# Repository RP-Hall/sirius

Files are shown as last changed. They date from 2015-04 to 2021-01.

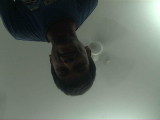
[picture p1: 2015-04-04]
MATLAB/matlab_camera/out_image.jpg

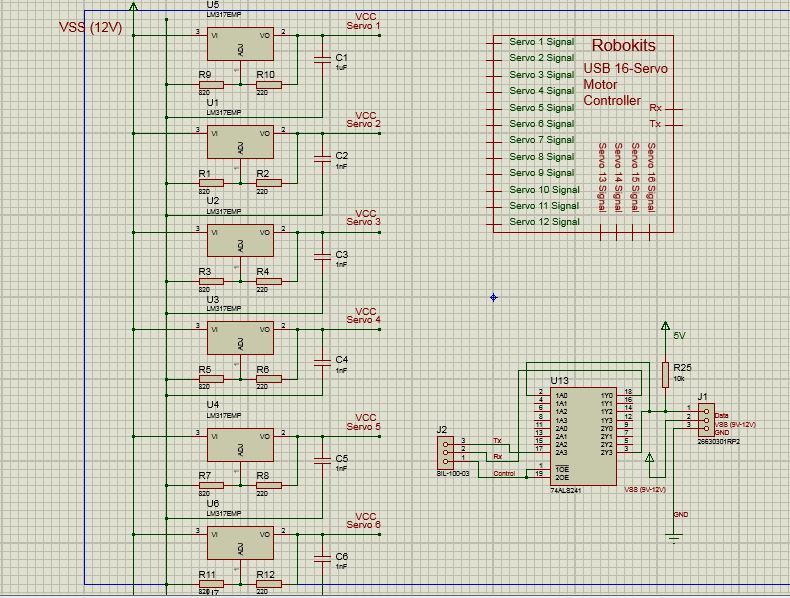
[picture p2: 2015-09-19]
Circuits/ckts.JPG

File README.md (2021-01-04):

# SIRIUS - A Wheel-Leg Transfigurable Robot

Sirius

## Video

Sirius Video (https://youtu.be/tceGkQNUUpM)

## Presentation
Sirius Presentation (http://www.slideshare.net/soumyadeepmukherjee17/hm2015-52970964)

## System Design

The following picture describe the system design of the robot:

Overall-Architecture

The following picture describes the control inputs to the robot:

Control-Architecture

## Circuitry

All schematics for embedded sub-systems are opened with 'Proteus' software

Sirius Circuitry

File: powerSirius.pdsprj: Proteus files for schematics

Schematic contents:  
1. Servo power system (Left)  
2. Robokits 16-Servo Motor Controller (Right Top)  
3. Communication System for Dynamixel (Right Bottom)

## File Explorer

Controller:  AtMEGA2560
Board used: [AtMEGA2560 Development Board](http://www.nex-robotics.com/products/microcontroller-development-boards/atmega2560-development-board.html)

### AVR
* Gait_Testing.c: File for testing gaits and debugging
* USART.c:	Functions for serial communication
* usart.h: 	Header for USART.c
* config.c:	Contains configurations for all gaits
* config.h: 	Header for config.c
* dynamixel.h dynamixel.c:	Files for running Dynamixels
* lcd.h lcd.c:	Files for showing output on LCD (connected at PORTD)	
* main.h: For running main process (different gaits)
* motion.h motion.c:	Files for motion of legs
* roboservo.h roboservo.c:	File for running servo motors

### Gaits
* backspider: Spider gait backwards
* home:	Home orientations
* littledog_gait: Dog gait
* little_gait_quasi: Quasi dog gait
* roll_gait: Wheel gait
* rotation_gait: Rotation
* spiderwalk: Spider gait

### MATLAB

* matlab_camera:
	** camera.m: Gets camera feed
	** imageConvert.py: Convert binary format image to jpeg
	** image_raw.txt: Raw image text file through camera
	** out_image.jpg: Output image
	** rawtoimage.m: MATLAB function to convert binary to image jpg

* matlab_inverse_kinematics:
	* acceptable_angles.txt: Text File to store acceptable angles after Gait Generation
	* angle_conversion_even.m: Convert Angles according to contraints for even angles
	* angle_conversion_odd: Convert Angles according to contraints for even angles
	* gait.m: File to calculate possible gaits
	* inversekinematics.m: Solves inverse kinematic equations
	* packet_angles.txt: Stores the angles to be sent as packet via serial
	* packet_generation.m: Generates packet format text file to be sent

### Serial_Testing
C++ Code for sending angles via serial communication.
* main.cpp:	main process
* serial.h serial.cpp: Serial Implementation

## Mechanical Design
All Solidworks Parts are uploaded.

Sirius Mechanical Design

Sirius Wheel Design

## References

[1] Kenjiro TADAKUMA(Osaka Univ.) et. al, Mechanical Design of the Wheel-Leg Hybrid Mobile Robot to Realize a Large Wheel Diameter. IEEE/RSJ International Conference on Intelligent Robots and Systems, Taipei, Taiwan, 2010  
[2] Carlos Queiroz, Nuno Gon ?calves and Paulo Menezes, A study on Static Gaits for a Four Leg Robot, CONTROL 2000, International Conference on, At Cambridge, UK  
[3] Nils Brynedal Ignell,Niclas Rasmusson and Johan Matsson, An overview of legged and wheeled robotic locomotion. IRCSE ’12. IDT Mini-conference on Interesting Results in Computer Science and Engineering, Sweden, 2012  
[4] Raibert, M. H. Legged Robots Communications of the ACM 499, June 1986 Volume 29 Number 6 http://www.universelle-automation.de/1980 Boston.pdf  
[5] Buckley D. 2011 http://davidbuckley.net/DB/HistoryMakers.htm  
[6] Arikawa, K., Hirose, S., 2007 Mechanical design of walking machines Philosophical Transactions of the Royal Society A 365  
[7] Heikkil,M.,Pietikinen,M.andSchmid,C.(2009),DescriptionofInter- est Regions with Local Binary Patterns. Pattern Recognition 42(3):425-436.  
[8] Christian Weiss,Nikolas Fechner,Matthias Stark and Andreas Zell,Comparison of Different Approaches to Vibration-based Terrain Clas- sification, ECMR07  

## Team
* Captains
	* Aditya Tiwari
	* Diwakar Paliwal
	* Vinay Varma
	* Sai Prasad Arkal
* Rest
	* Keshav Sarraf
	* Soumyadeep Mukherjee
	* Rishal Raj
	* Vishnu Sharma
	* Aman Gupta
	* Nipurn Gulgulia
	* Raushan Kumar
	* Kawaljeet Kumar
	* Divya Prakash
	* Seemant Jay
	* Rahul Singh
	* Kumar Abhinav

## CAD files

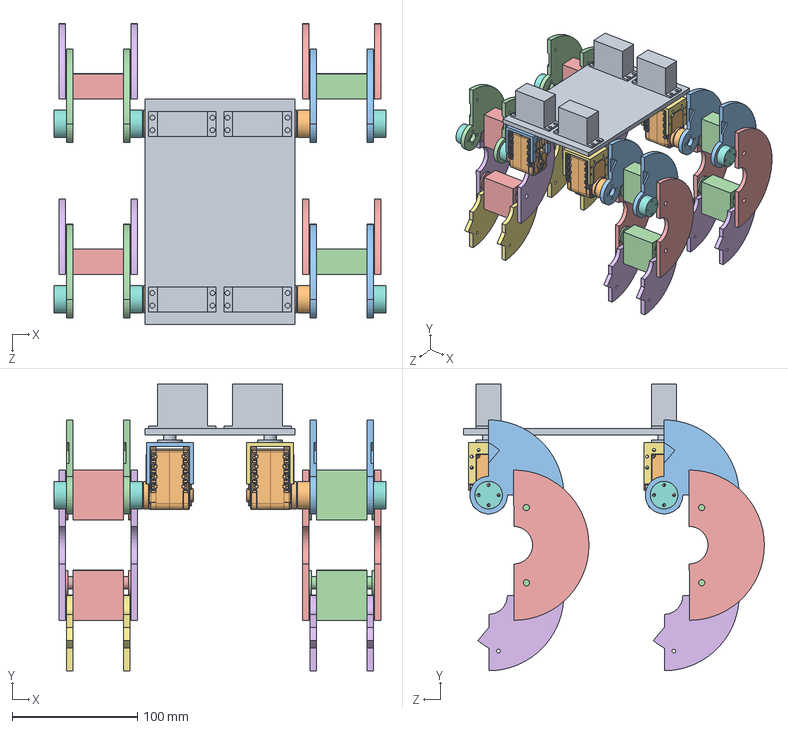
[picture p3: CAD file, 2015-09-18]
MechD/PsyBot Assembly.SLDASM
265.0 x 228.7 x 240.1 mm
Base
Dynamixel AX12 x 4
Arm Connector x 2
thigh x 4
servo x 4
calf x 4
foot x 4
DynExtender x 6
Topservo x 4
MirrorDynExtender x 2
Mirrorthigh x 4
Mirrorservo x 4
Mirrorcalf x 4
Mirrorfoot x 4
MirrorArm Connector x 2

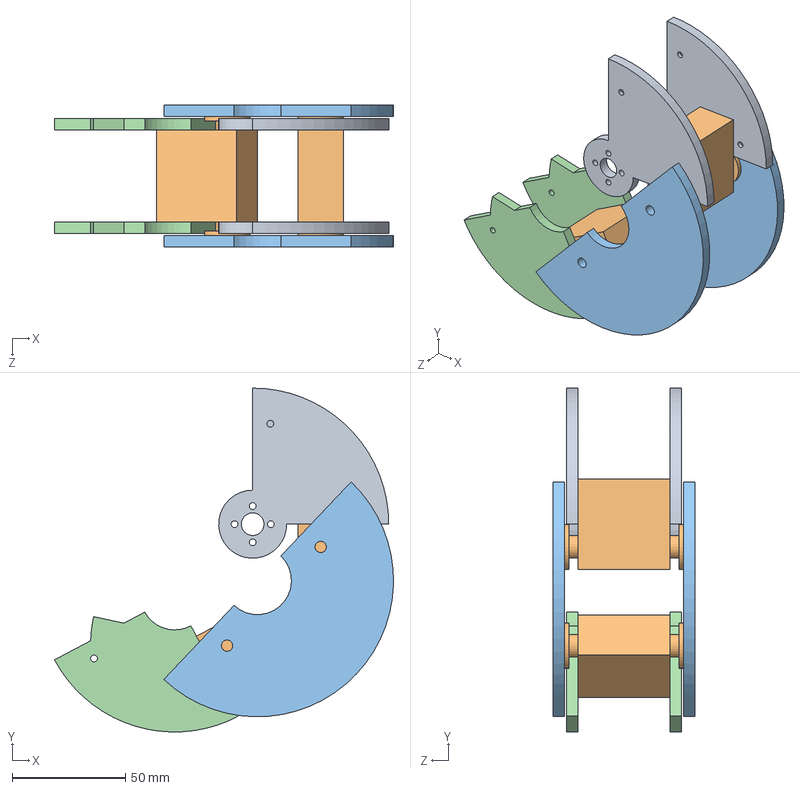
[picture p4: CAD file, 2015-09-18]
MechD/PsyWheel.SLDASM
149.4 x 151.6 x 62.5 mm
thigh x 2
servo x 2
calf x 2
foot x 2

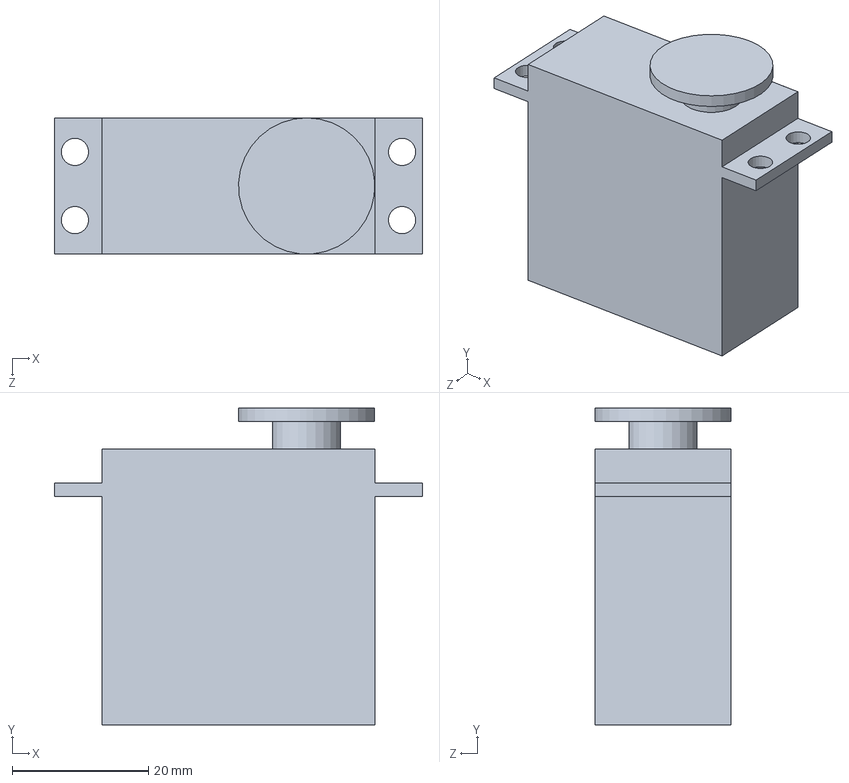
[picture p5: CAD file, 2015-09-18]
MechD/Topservo.SLDPRT
54.0 x 46.5 x 20.0 mm

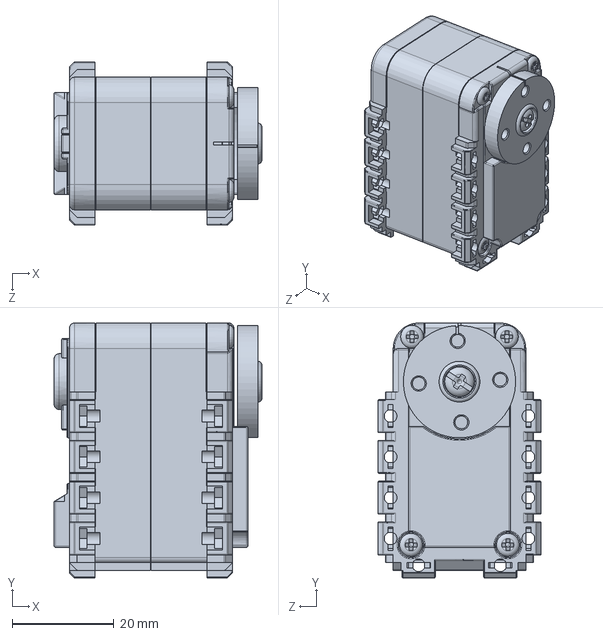
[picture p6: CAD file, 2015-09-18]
MechD/Dynamixel AX12.SLDPRT
40.8 x 50.0 x 32.0 mm

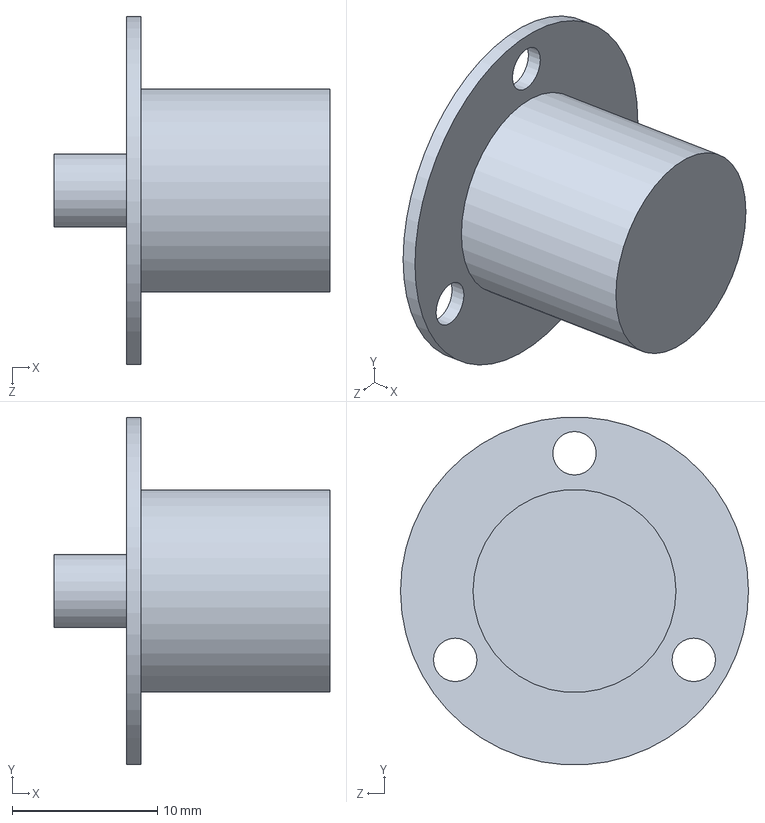
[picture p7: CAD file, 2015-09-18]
MechD/SlipRing.SLDPRT
19.0 x 24.0 x 24.0 mm

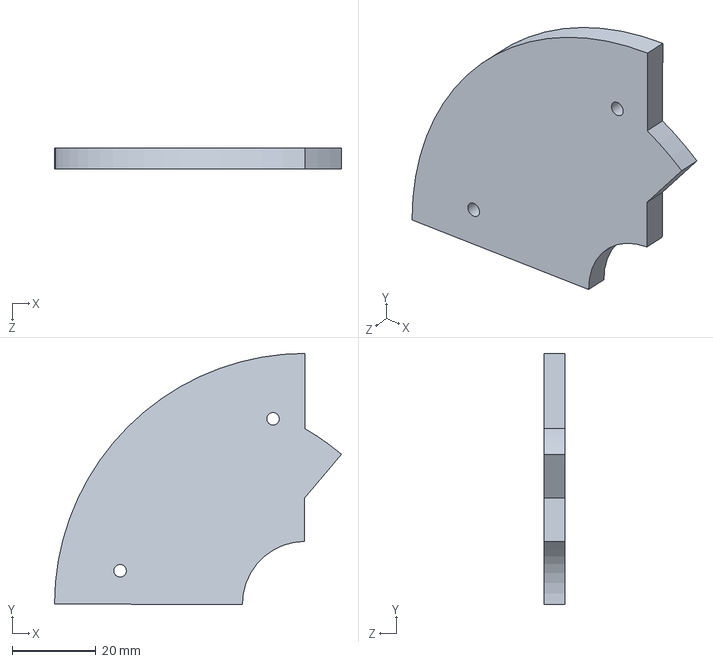
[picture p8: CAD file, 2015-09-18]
MechD/foot.SLDPRT
68.7 x 60.1 x 5.00 mm

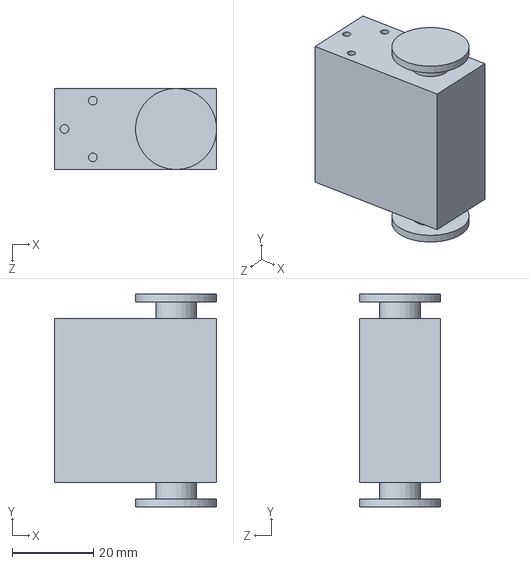
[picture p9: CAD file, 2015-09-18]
MechD/servo.SLDPRT
40.0 x 52.5 x 20.0 mm

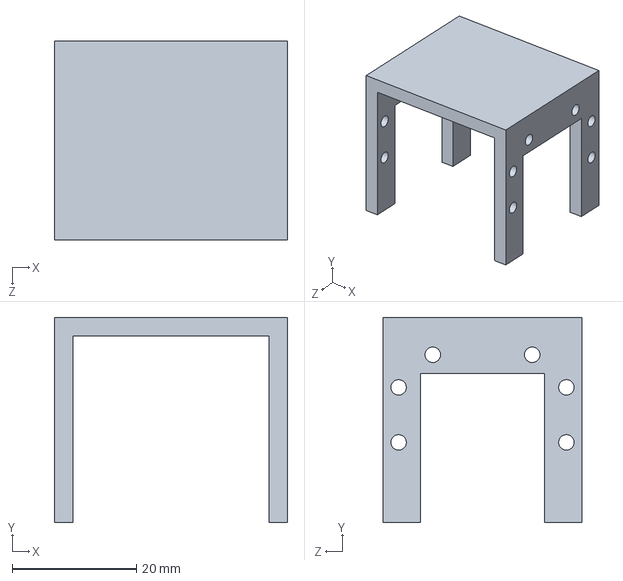
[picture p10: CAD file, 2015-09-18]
MechD/Arm Connector.SLDPRT
37.5 x 33.0 x 32.0 mm

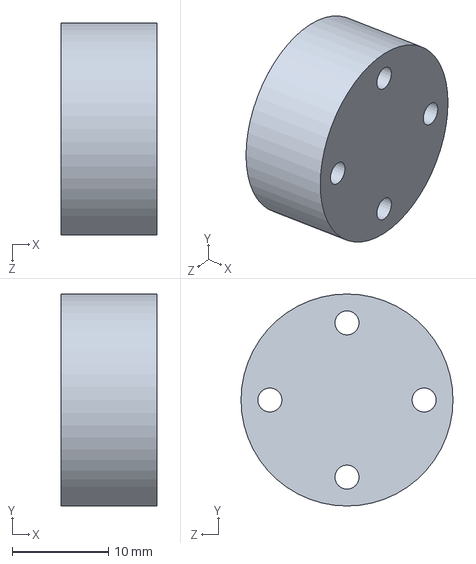
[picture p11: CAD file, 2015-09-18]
MechD/DynExtender.SLDPRT
10.0 x 22.0 x 22.0 mm

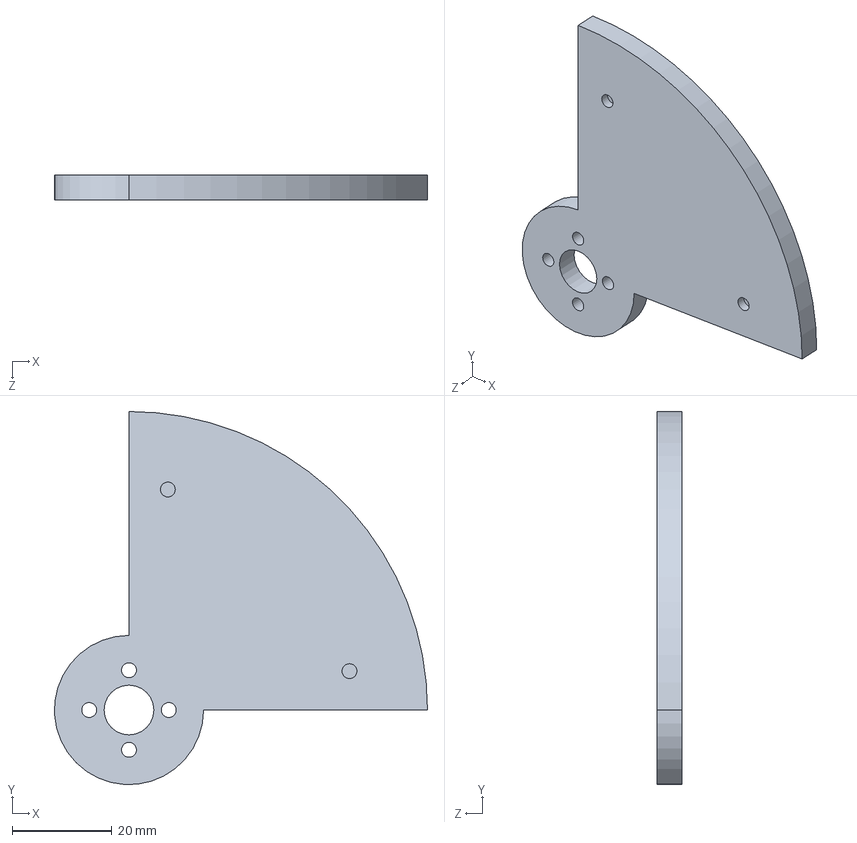
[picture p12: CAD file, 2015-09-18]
MechD/thigh.SLDPRT
75.0 x 75.0 x 5.00 mm

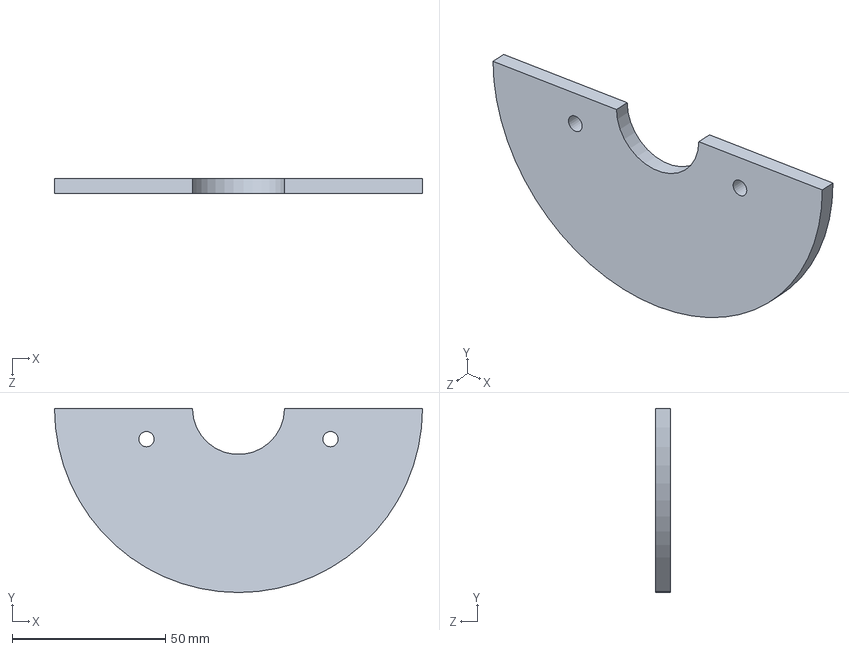
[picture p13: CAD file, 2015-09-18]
MechD/calf.SLDPRT
120.0 x 60.0 x 5.00 mm

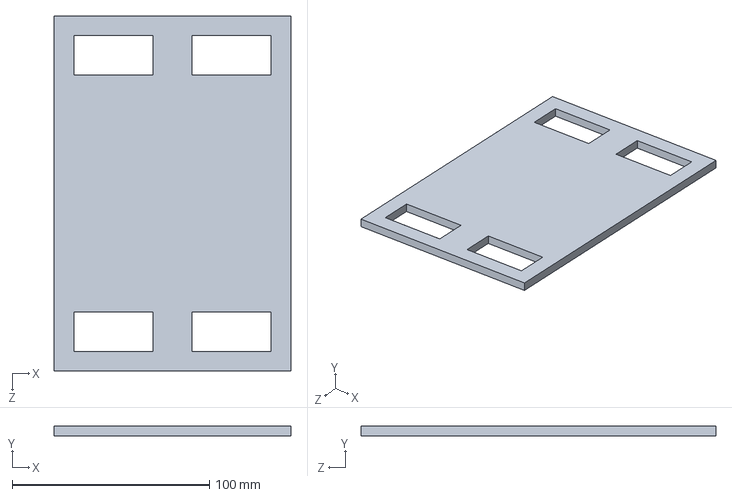
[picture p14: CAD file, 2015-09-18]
MechD/Base.SLDPRT
120.0 x 5.00 x 180.0 mm

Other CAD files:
MechD/MirrorPsyWheel.SLDASM
MechD/MirrorArm Connector.SLDPRT
MechD/MirrorDynExtender.SLDPRT
MechD/Mirrorthigh.SLDPRT
MechD/Mirrorservo.SLDPRT
MechD/Mirrorcalf.SLDPRT
MechD/Mirrorfoot.SLDPRT

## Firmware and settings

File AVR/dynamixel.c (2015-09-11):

/*
 * Dyn_test.c
 *
 * Created: 3/15/2015 11:12:32 AM
 *  Author: mukherjee
 */ 

#define F_CPU 14745600UL

#include <avr/io.h>
#include <avr/interrupt.h>
#include <inttypes.h>
#include <util/delay.h>
#include "dynamixel.h"

// To be coverted into program memory
//char RESULT = SUCCESS;
int current_sending_length = MAX_SENT_PKT;
int current_receiving_length = MAX_RECV_PKT;
int status1 = 0;
int rec_index = 0;

char receive_buffer[MAX_RECV_PKT];
char send_buffer[MAX_SENT_PKT];

ISR(USART3_RX_vect)
{
	//cli();
	receive_buffer[rec_index] = UDR3;

	rec_index++;
	if(rec_index == current_receiving_length)
	{
		rec_index = 0;
		if(receive_buffer[ERROR_INDX] == SUCCESS)
		{	status1 = 1;
		//disable_recv;
		}
		else
		{	
			//lcd_cursor(1,1);
			//lcd_string("error receiving");
			lcd_cursor(2,1);
			print_receive_pkt();
		}			
		//PORTJ |= (1<<5);
		
	}
	
	//	sei();
}

void UART3_init()
{
	UCSR3A = 0x00;
	UCSR3C=(1<<UCSZ31)|(1<<UCSZ30); // 8 bit char length
	UBRR3L = 15;					// 57600 baud
	UBRR3H = 0x00;
	//UCSR3B = 0x98;
	UCSR3B=(1<<RXCIE3)|(1<<TXEN3);	// enable Rx int and Tx
}	

void buffer_init()
{
	int i;
	
	for (i=0;i<MAX_SENT_PKT;i++)
	{
		send_buffer[i] = 0;
	}
	for (i=0;i<MAX_RECV_PKT;i++)
	{
		receive_buffer[i] = 0;
	}
}

void dynamixel_init()
{
	buffer_init();
	UART3_init();
	lcd_init();
	DDRJ = (1<<5);
}

void send_pkt()
{
	int i;
	PORTJ |= (1<<5);
	disable_recv;
	for(i=0;i<current_sending_length;i++)
	{
		while ( !( UCSR3A & (1<<UDRE3)) );
		UDR3 = send_buffer[i];
	}
	_delay_us(450);//default 300 for57600 baud
	enable_recv;
	PORTJ &= ~(1<<5);
}

void print_receive_pkt()
{
	int i;
	for (i=0;i<current_receiving_length;i++)
	{
		print_hex(receive_buffer[i]);
	}
}

void print_send_pkt()
{
	int i;
	for (i=3;i<current_sending_length;i++)
	{
		print_hex(send_buffer[i]);
	}
}

char get_checksum(int index)
{
	int i;char sum = 0;
	for(i=2;i<index;i++)
		sum+=send_buffer[i];
	return ~(sum);
}

void move2pos(char id,int pos,int vel)
{
	char posL,posH,velL,velH;
	
	pos = (int)(pos*3.41) + 665;
	
	posL = pos & 0x00FF;
	posH = ((pos & 0xFF00)>>8);
	velL = vel & 0x00FF;
	velH = ((vel & 0xFF00)>>8);
	
	send_buffer[0] = HEADER1;
	send_buffer[1] = HEADER2;
	send_buffer[2] = id;
	send_buffer[3] = MOVE_SENT_PKT_LENGTH-4;
	send_buffer[4] = INST_WRITE;
	send_buffer[5] = GOAL_POS_ADD; 
	send_buffer[6] = posL;
	send_buffer[7] = posH;
	send_buffer[8] = velL;
	send_buffer[9] = velH;
	send_buffer[10] = get_checksum(10);
		
	current_sending_length = MOVE_SENT_PKT_LENGTH;
	current_receiving_length = MOVE_RECV_PKT_LENGTH;
	display_clear();
	print_send_pkt();
	send_pkt();
}

int current_pos(char id)
{
	int pos = -1;
	
	send_buffer[0] = HEADER1;
	send_buffer[1] = HEADER2;
	send_buffer[2] = id;
	send_buffer[3] = READ_SENT_PKT_LENGTH-4;
	send_buffer[4] = INST_READ;
	send_buffer[5] = 0x24; 
	send_buffer[6] = 0x02;
	send_buffer[7] = get_checksum(7);
	
	current_sending_length = READ_SENT_PKT_LENGTH;
	current_receiving_length = READ_RECV_PKT_LENGTH+1;
	
	send_pkt();
	_delay_ms(3);											// TRY TO REMOVE THIS
	//while(!(status1));
	if (receive_buffer[ERROR_INDX]==SUCCESS)	
	{	
		_delay_ms(1);
		//lcd_cursor(2,8);
		pos = ((int)(receive_buffer[6]&0x00FF)<<8)+(int)(receive_buffer[5]&0x00FF);
	
	}	
	return pos;
}

int is_moving(char id)
{
	int moving = 0;
	
	send_buffer[0] = HEADER1;
	send_buffer[1] = HEADER2;
	send_buffer[2] = id;
	send_buffer[3] = READ_SENT_PKT_LENGTH-4;
	send_buffer[4] = INST_READ;
	send_buffer[5] = 0x2E;
	send_buffer[6] = 0x01;
	send_buffer[7] = get_checksum(7);
	
	current_sending_length = READ_SENT_PKT_LENGTH;
	current_receiving_length = READ_RECV_PKT_LENGTH;
	
	send_pkt();
	_delay_ms(2);										// TRY TO REMOVE THIS
	//while(!(status1));
	if (receive_buffer[ERROR_INDX]==SUCCESS)
	{
		//lcd_cursor(2,8);
		if(receive_buffer[5])
			moving = 1;
	}
	return moving;
}

void wheel_mode(char id)
{	
	send_buffer[0] = HEADER1;
	send_buffer[1] = HEADER2;
	send_buffer[2] = id;
	send_buffer[3] = MOVE_SENT_PKT_LENGTH-4;
	send_buffer[4] = INST_WRITE;
	send_buffer[5] = 0x06;
	send_buffer[6] = 0x00;
	send_buffer[7] = 0x00;
	send_buffer[8] = 0x00;
	send_buffer[9] = 0x00;
	send_buffer[10] = get_checksum(10);
	
	current_sending_length = MOVE_SENT_PKT_LENGTH;
	current_receiving_length = MOVE_RECV_PKT_LENGTH;
	
	send_pkt();
	//_delay_us(1000);
	//wheel_mode_speed(id,0);
	//_delay_ms(1);
	
}

void wheel_mode_speed(char id,int vel)					// Vel argument -1023 to 1023 for CCW to CW rotation
{
	char velL,velH;
	
	if (vel<0)
	{
		vel = -vel;
		velH = 0x00;					// Direction bit set CCW
	}
	else
		velH = 0x04;					// Direction bit set CW
	
	velL = vel & 0x00FF;
	velH |= (vel & 0xFF00)>>8;
	
	send_buffer[0] = HEADER1;
	send_buffer[1] = HEADER2;
	send_buffer[2] = id;
	send_buffer[3] = MOVE_SENT_PKT_LENGTH-6;
	send_buffer[4] = INST_WRITE;
	send_buffer[5] = 0x20;				// Address for velocity
	send_buffer[6] = velL;
	send_buffer[7] = velH;
	send_buffer[8] = get_checksum(8);
	
	current_sending_length = MOVE_SENT_PKT_LENGTH-2;
	current_receiving_length = MOVE_RECV_PKT_LENGTH;
	
	//display_clear();
//	lcd_print(1,1,vel,4);
	send_pkt();
	_delay_us(650);
}

void legged_mode(char id)
{
	wheel_mode_speed(id,0);
	print_receive_pkt();
	_delay_us(650);
	
	send_buffer[0] = HEADER1;
	send_buffer[1] = HEADER2;
	send_buffer[2] = id;
	send_buffer[3] = MOVE_SENT_PKT_LENGTH-4;
	send_buffer[4] = INST_WRITE;
	send_buffer[5] = 0x06;
	send_buffer[6] = 0x00;
	send_buffer[7] = 0x00;
	send_buffer[8] = 0xff;
	send_buffer[9] = 0x03;
	send_buffer[10] = get_checksum(10);
	
	current_sending_length = MOVE_SENT_PKT_LENGTH;
	current_receiving_length = MOVE_RECV_PKT_LENGTH;
	
	send_pkt();
	_delay_us(650);
}

void update_pos(char id,int pos,int vel)
{
	char posL,posH,velL,velH;
	
	pos = (int)(pos*3.41)+665;
	
	posL = pos & 0x00FF;
	posH = (pos & 0xFF00)>>8;
	velL = vel & 0x00FF;
	velH = (vel & 0xFF00)>>8;
	
	send_buffer[0] = HEADER1;
	send_buffer[1] = HEADER2;
	send_buffer[2] = id;
	send_buffer[3] = MOVE_SENT_PKT_LENGTH-4;
	send_buffer[4] = INST_REG_WRITE;
	send_buffer[5] = GOAL_POS_ADD;
	send_buffer[6] = posL;
	send_buffer[7] = posH;
	send_buffer[8] = velL;
	send_buffer[9] = velH;
	send_buffer[10] = get_checksum(10);
	
	current_sending_length = MOVE_SENT_PKT_LENGTH;
	current_receiving_length = MOVE_RECV_PKT_LENGTH;
	
	send_pkt();
}

void wheel_mode_speed_update(char id,int vel)					// Vel argument -1023 to 1023 for CCW to CW rotation
{
	char velL,velH;
	
	if (vel<0)
	{
		vel = -vel;
		velH = 0x00;					// Direction bit set CCW
	}
	else
	{	
		velH = 0x04;					// Direction bit set CW
	}
		
	velL = vel & 0x00FF;
	velH |= (vel & 0xFF00)>>8;
	
	send_buffer[0] = HEADER1;
	send_buffer[1] = HEADER2;
	send_buffer[2] = id;
	send_buffer[3] = MOVE_SENT_PKT_LENGTH-6;
	send_buffer[4] = INST_REG_WRITE;
	send_buffer[5] = 0x20;				// Address for velocity
	send_buffer[6] = velL;
	send_buffer[7] = velH;
	send_buffer[8] = get_checksum(8);
	
	current_sending_length = MOVE_SENT_PKT_LENGTH-2;
	current_receiving_length = MOVE_RECV_PKT_LENGTH;
	
	//display_clear();
	//lcd_print(1,1,vel,4);
	send_pkt();
	//_delay_ms(5);
	_delay_us(650);
}

void move_dyn_sync()
{
	send_buffer[0] = HEADER1;
	send_buffer[1] = HEADER2;
	send_buffer[2] = 0xFE;						//broadcast id
	send_buffer[3] = 2;
	send_buffer[4] = INST_SYNC_MOVE;
	send_buffer[5] = 0xFA;
	
	current_sending_length = 6;
	current_receiving_length = 0;
	
	send_pkt();
}


void stop_wheel_mode(char id, int angle)
{
	send_buffer[0] = HEADER1;
	send_buffer[1] = HEADER2;
	send_buffer[2] = id;						//broadcast id
	send_buffer[3] = 0x05;
	send_buffer[4] = INST_REG_WRITE;
	send_buffer[5] = 0x1E;
	send_buffer[6] = (angle & 0x00FF);
	send_buffer[7] = ((angle>>8) & 0x00FF);
	
	send_buffer[8] = get_checksum(8);
	
		
	current_sending_length = 9;
	current_receiving_length = 6;
	
	send_pkt();
	_delay_ms(100);
	print_receive_pkt();
	_delay_us(1000);
	
	send_buffer[3] = 0x07;
	send_buffer[5] = 0x06;
	send_buffer[6] = 0x00;
	send_buffer[7] = 0x00;
	send_buffer[8] = 0xFF;
	send_buffer[9] = 0x03;
	
	send_buffer[10] = get_checksum(10);
	
	current_sending_length = 11;
	current_receiving_length = 6;
	
	send_pkt();
	_delay_us(650);
	print_receive_pkt();
	_delay_ms(10);
	
	
	send_buffer[3] = 2;
	send_buffer[4] = INST_SYNC_MOVE;
	
	send_buffer[5] = get_checksum(5);
	
	current_sending_length = 6;
	current_receiving_length = 6;
	
	send_pkt();
	_delay_ms(10);
	//print_receive_pkt();
}

/*

int main(void)
{
	DDRB = 0xff;PORTB = 0;int now=0;
		
	dynamixel_init();
	lcd_init();
	
	sei();
	
	
	wheel_mode(6);
	_delay_us(1000);
	
	wheel_mode_speed(6,0x0200);
	print_receive_pkt();
	_delay_ms(4000);
	
	//stop_wheel_mode(6,0x0000);
	//legged_mode(6);
	while(1)
	{
		
		
	}
	
	PORTB = 0xff;
}
*/
/*	
int main(void)
{
	DDRB = 0xff;PORTB = 0;DDRF =0xff;PORTF = 0;
	//PORTK = 0xff;
	
	cli();
	dynamixel_init();
	
	
	char data[11] = {0xFF, 0xFF, 0x06, 0x07, 0x03, 0x1E, 0x00, 0x02, 0x00, 0x02, 0xD2};
	//	char data[11] = {0xFF, 0xFF, 0x01, 0x07, 0x03, 0x1E, 0x00, 0x02, 0x00, 0x02, 0xD2};
	//char data[8] = {0xff, 0xff, 0x01, 0x04, 0x02, 0x00, 0x03, 0xf5};
	int i=0;
	char check_sum = 0;
	for (i=2;i<10;i++)
	{
		check_sum+= data[i];
	}
	data[10] = ~(check_sum & 0x00FF);
	
	
	sei();
	while(1)
	{
		
		PORTK = 0xff;
		for(i=0;i<11;i++)
		{		
			while ( !( UCSR3A & (1<<UDRE3)) );
			UDR3 = data[i];
		}
		_delay_us(100);
		current_receiving_length = 6;
		UCSR3B |=(1<<RXEN3);
		//enable_recv;
		PORTK = 0x00;
		
		while(!(status1))
		{
			PORTB = 0xff;
			_delay_ms(500);
			PORTB = 0x00;
			_delay_ms(500);
		}
		break;
	}
	print_receive_pkt();
	PORTB = 0xff;
}*/	

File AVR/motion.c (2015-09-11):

/* Robot Motor Configuration

			Front Side from Top(wheel Number)
			
				6			4
			
			    1			2
				
			Front Side from top(Servo ID)                 
			
		30deg->		1(2)			4(1)		  			
		150deg->	2				3	
		Top			5				6
				
		30deg->		11(3)			10(4)
		150deg->	12				9
		TOP			7				8		

*/
#define F_CPU 14745600UL

#include <avr/io.h>
#include <avr/interrupt.h>
#include <inttypes.h>
#include <util/delay.h>
#include "motion.h"
#include "lcd.h"
#include "roboservo.h"
#include "dynamixel.h"


// Move all the motors to destination together
void move_bot()
{
	send_robo_packet();				
	move_dyn_sync();
}

// move legs to safe position(closed)
void go_to_safe_angle()
{
	update_wheel_angle(1,BASE_ANGLE_YAW6,SAFE_ANGLE,SAFE_ANGLE, 0);
	update_wheel_angle(2,BASE_ANGLE_YAW5,SAFE_ANGLE,SAFE_ANGLE, 0);
	update_wheel_angle(3,BASE_ANGLE_YAW7,SAFE_ANGLE,SAFE_ANGLE, 0);
	update_wheel_angle(4,BASE_ANGLE_YAW8,SAFE_ANGLE,SAFE_ANGLE, 0);
}

// move to base angle for yaw motors i.e. facing straight
void go_to_base_yaw()
{
	update_robo_angle(5,BASE_ANGLE_YAW5);
	update_robo_angle(6,BASE_ANGLE_YAW6);
	update_robo_angle(7,BASE_ANGLE_YAW7);
	update_robo_angle(8,BASE_ANGLE_YAW8);
	send_robo_packet();
}

// move dynamixels to uprght position
void go_to_base_dynamixel()
{
	move2pos(1,0,512);
	move2pos(2,0,512);
	move2pos(3,0,512);
	move2pos(4,0,512);
}

// move motors in quarter with cut to their base angle
void go_to_base_cut()
{
	update_robo_angle(1,BASE_ANGLE_CUT1);
	update_robo_angle(3,BASE_ANGLE_CUT3);
	update_robo_angle(9,BASE_ANGLE_CUT9);
	update_robo_angle(11,BASE_ANGLE_CUT11);
}

// move motors in quarter with notch to their base angle
void go_to_base_notch()
{
	update_robo_angle(2,BASE_ANGLE_NOTCH2);
	update_robo_angle(4,BASE_ANGLE_NOTCH4);
	update_robo_angle(10,BASE_ANGLE_NOTCH10);
	update_robo_angle(12,BASE_ANGLE_NOTCH12);
}

// move the leg to desired position
void move_wheel_angle(char id_leg,int yaw, int cut_angle, int notch_angle)
{
	switch (id_leg){
		case 2:
		update_robo_angle(2,notch_angle);	update_robo_angle(1,cut_angle);	update_robo_angle(5,yaw);
		send_robo_packet(12);break;
		case 1:
		update_robo_angle(4,notch_angle);	update_robo_angle(3,cut_angle);	update_robo_angle(6,yaw);
		send_robo_packet(12);break;
		case 3:
		update_robo_angle(10,notch_angle);	update_robo_angle(9,cut_angle); update_robo_angle(8,yaw);
		send_robo_packet(12);break;
		case 4:
		update_robo_angle(12,notch_angle);	update_robo_angle(11,cut_angle); update_robo_angle(7,yaw);
		send_robo_packet(12);break;
	}
}


// update the destination position of legs to be moved in sync later
void update_wheel_angle(char id_leg,int yaw, int cut_angle, int notch_angle,int dyn_angle)
{
	switch (id_leg){
		case 2:
		update_robo_angle(2,notch_angle);	update_robo_angle(1,cut_angle);	update_robo_angle(5,yaw); update_pos(id_leg, dyn_angle, 512);
		break;
		case 1:
		update_robo_angle(4,notch_angle);	update_robo_angle(3,cut_angle);	update_robo_angle(6,yaw);update_pos(id_leg,dyn_angle, 512);
		break;
		case 3:
		update_robo_angle(10,notch_angle);	update_robo_angle(9,cut_angle); update_robo_angle(7,yaw);update_pos(id_leg,dyn_angle, 512);
		break;
		case 4:
		update_robo_angle(12,notch_angle);	update_robo_angle(11,cut_angle); update_robo_angle(8,yaw);update_pos(id_leg,dyn_angle, 512);
		break;
	}
}

// sequence for going to leg mode and standing
void open_wheel()
{
	go_to_base_dynamixel();
	update_wheel_angle(1,BASE_ANGLE_YAW6,BASE_ANGLE_CUT3,BASE_ANGLE_NOTCH4, 0);
	update_wheel_angle(2,BASE_ANGLE_YAW5,BASE_ANGLE_CUT1,BASE_ANGLE_NOTCH2, 0);
	update_wheel_angle(3,BASE_ANGLE_YAW7,BASE_ANGLE_CUT9,BASE_ANGLE_NOTCH10, 0);
	update_wheel_angle(4,BASE_ANGLE_YAW8,BASE_ANGLE_CUT11,BASE_ANGLE_NOTCH12, 0);
	send_robo_packet();_delay_ms(1000);
	update_wheel_angle(1,BASE_ANGLE_YAW6,BASE_ANGLE_CUT3,30, 0);
	update_wheel_angle(2,BASE_ANGLE_YAW5,BASE_ANGLE_CUT1,30, 0);
	update_wheel_angle(3,BASE_ANGLE_YAW7,BASE_ANGLE_CUT9,30, 0);
	update_wheel_angle(4,BASE_ANGLE_YAW8,BASE_ANGLE_CUT11,30, 0);
	send_robo_packet();_delay_ms(1000);
	update_wheel_angle(1,BASE_ANGLE_YAW6,30,45, 0);
	update_wheel_angle(2,BASE_ANGLE_YAW5,30,45, 0);
	update_wheel_angle(3,BASE_ANGLE_YAW7,30,45, 0);
	update_wheel_angle(4,BASE_ANGLE_YAW8,30,45, 0);
	send_robo_packet();_delay_ms(1000);
	update_wheel_angle(1,BASE_ANGLE_YAW6,60,45, 0);
	update_wheel_angle(2,BASE_ANGLE_YAW5,60,45, 0);
	update_wheel_angle(3,BASE_ANGLE_YAW7,60,45, 0);
	update_wheel_angle(4,BASE_ANGLE_YAW8,60,45, 0);
	send_robo_packet();_delay_ms(1000);
	update_wheel_angle(1,BASE_ANGLE_YAW6,85,60, 0);
	update_wheel_angle(2,BASE_ANGLE_YAW5,85,60, 0);
	update_wheel_angle(3,BASE_ANGLE_YAW7,85,60, 0);
	update_wheel_angle(4,BASE_ANGLE_YAW8,85,60, 0);
	send_robo_packet();_delay_ms(1000);
	update_wheel_angle(1,BASE_ANGLE_YAW6,85,70, 0);
	update_wheel_angle(2,BASE_ANGLE_YAW5,85,70, 0);
	update_wheel_angle(3,BASE_ANGLE_YAW7,85,70, 0);
	update_wheel_angle(4,BASE_ANGLE_YAW8,85,70, 0);
	send_robo_packet();_delay_ms(1000);
	
}


// sequence for closing the legs
void close_wheel()
{
	go_to_base_dynamixel();
	update_wheel_angle(1,BASE_ANGLE_YAW6,85,70, 0);
	update_wheel_angle(2,BASE_ANGLE_YAW5,85,70, 0);
	update_wheel_angle(3,BASE_ANGLE_YAW7,85,70, 0);
	update_wheel_angle(4,BASE_ANGLE_YAW8,85,70, 0);
	send_robo_packet();_delay_ms(500);/*
	update_wheel_angle(1,BASE_ANGLE_YAW6,85,60);
	update_wheel_angle(2,BASE_ANGLE_YAW5,85,60);
	update_wheel_angle(3,BASE_ANGLE_YAW7,85,60);
	update_wheel_angle(4,BASE_ANGLE_YAW8,85,60);
	send_robo_packet();_delay_ms(500);*/
	update_wheel_angle(1,BASE_ANGLE_YAW6,60,45, 0);
	update_wheel_angle(2,BASE_ANGLE_YAW5,60,45, 0);
	update_wheel_angle(3,BASE_ANGLE_YAW7,60,45, 0);
	update_wheel_angle(4,BASE_ANGLE_YAW8,60,45, 0);
	send_robo_packet();_delay_ms(500);/*
	update_wheel_angle(1,BASE_ANGLE_YAW6,30,45);
	update_wheel_angle(2,BASE_ANGLE_YAW5,30,45);
	update_wheel_angle(3,BASE_ANGLE_YAW7,30,45);
	update_wheel_angle(4,BASE_ANGLE_YAW8,30,45);
	send_robo_packet();_delay_ms(500);
	update_wheel_angle(1,BASE_ANGLE_YAW6,BASE_ANGLE_CUT3,30);
	update_wheel_angle(2,BASE_ANGLE_YAW5,BASE_ANGLE_CUT1,30);
	update_wheel_angle(3,BASE_ANGLE_YAW7,BASE_ANGLE_CUT9,30);
	update_wheel_angle(4,BASE_ANGLE_YAW8,BASE_ANGLE_CUT11,30);
	send_robo_packet();_delay_ms(500);*/
	update_wheel_angle(1,BASE_ANGLE_YAW6,BASE_ANGLE_CUT3,BASE_ANGLE_NOTCH4, 0);
	update_wheel_angle(2,BASE_ANGLE_YAW5,BASE_ANGLE_CUT1,BASE_ANGLE_NOTCH2, 0);
	update_wheel_angle(3,BASE_ANGLE_YAW7,BASE_ANGLE_CUT9,BASE_ANGLE_NOTCH10, 0);
	update_wheel_angle(4,BASE_ANGLE_YAW8,BASE_ANGLE_CUT11,BASE_ANGLE_NOTCH12, 0);
	send_robo_packet();_delay_ms(500);
}

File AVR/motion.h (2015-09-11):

#include <avr/io.h>
#include <util/delay.h>
#include "lcd.h"
#include "roboservo.h"
#include "dynamixel.h"

#ifndef _motion_H
#define _motion_H

#define BASE_ANGLE_YAW5 -1
#define BASE_ANGLE_YAW6 1
#define BASE_ANGLE_YAW7 0
#define BASE_ANGLE_YAW8 -1
#define BASE_ANGLE_CUT1 -9
#define BASE_ANGLE_CUT3 0
#define BASE_ANGLE_CUT9 0
#define BASE_ANGLE_CUT11 0
#define BASE_ANGLE_NOTCH2 -7
#define BASE_ANGLE_NOTCH4 -6
#define BASE_ANGLE_NOTCH10 -10
#define BASE_ANGLE_NOTCH12 -5

#define SAFE_ANGLE 30

void move_bot();

void go_to_safe_angle();

void go_to_base_yaw();

void go_to_base_dynamixel();

void go_to_base_cut();

void go_to_base_notch();

void move_wheel_angle(char id_leg,int yaw, int cut_angle, int notch_angle);

void update_wheel_angle(char id_leg,int yaw, int cut_angle, int notch_angle,int dyn_angle);

void open_wheel();

void close_wheel();

#endif

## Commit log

2015-03-31 Single Leg Added
2015-03-31 Single Leg Edited
2015-04-01 Broken Packet Function Added
    [main.cpp]
2015-04-01 Matrix Added for Yaw Motor
2015-04-04 Problems Removed and Solved
    [main.cpp]
2015-09-18 SW Files Added
    [Arm Connector.SLDPRT, Base.SLDPRT, DynExtender.SLDPRT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]
2015-09-19 Circuits Added
